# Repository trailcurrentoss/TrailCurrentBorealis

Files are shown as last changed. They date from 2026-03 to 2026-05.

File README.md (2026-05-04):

# TrailCurrent Borealis

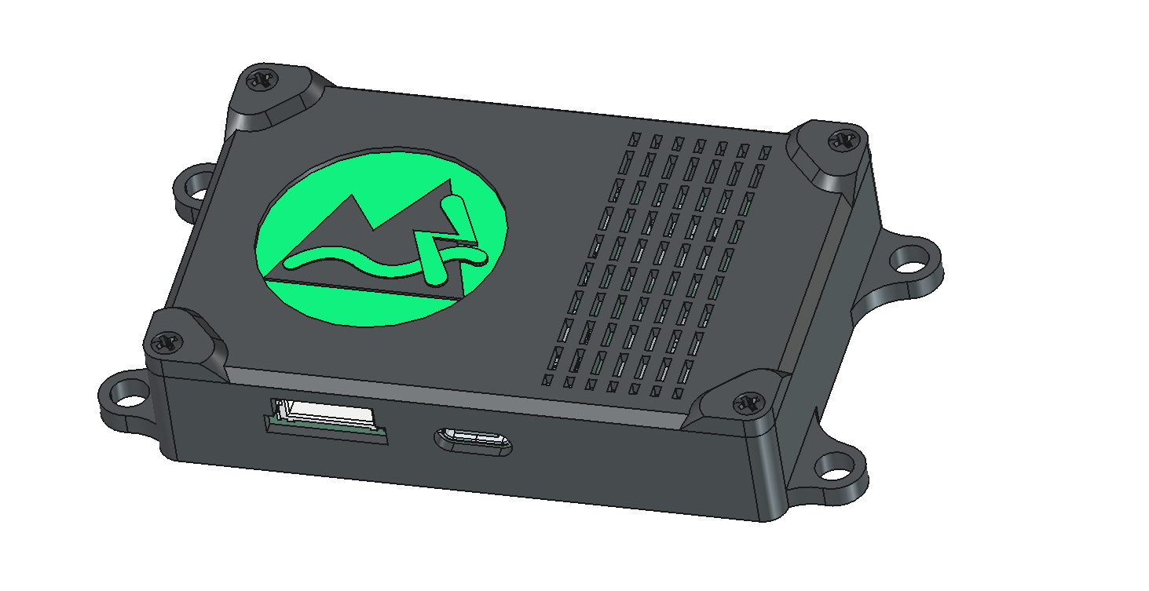
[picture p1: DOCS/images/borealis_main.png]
TrailCurrent Borealis


Environmental and safety sensor node for toy haulers, RVs, and similar enclosed living spaces. Measures temperature, humidity, real CO2, VOC index, carbon monoxide, and propane / LPG levels, then broadcasts readings over a CAN bus. Supports over-the-air (OTA) firmware updates, WiFi credential provisioning via CAN, and network discovery for integration with TrailCurrent Headwaters.

## Hardware

- **MCU board:** [Waveshare ESP32-S3-RS485-CAN](https://www.waveshare.com/esp32-s3-rs485-can.htm)
  - ESP32-S3R8 (8MB PSRAM, external 16MB flash)
  - Built-in isolated CAN transceiver (TJA1051) on GPIO15/16
  - Built-in isolated RS485 transceiver (unused by Borealis)
  - External PCF85063AT RTC
  - 7-36V DC input or 5V USB-C
- **CO2 / temp / humidity:** DFRobot SEN0536 (Sensirion SCD41, photoacoustic NDIR)
- **VOC trending:** DFRobot SEN0394 (Sensirion SGP40, VOC Index 1-500)
- **Carbon monoxide:** DFRobot SEN0466 (factory-calibrated electrochemical, 0-1000 ppm)
- **Propane / LPG:** DFRobot SEN0131 (MQ-6 with adjustable potentiometer)

### Pin Assignments

| GPIO | Function |
|---|---|
| 5 | I2C SDA (SCD41, SGP40, SEN0466) |
| 6 | I2C SCL (SCD41, SGP40, SEN0466) |
| 3 | MQ-6 analog input (ADC1_CH2, via 10k/15k divider) |
| 15 | CAN TX (internal transceiver) |
| 16 | CAN RX (internal transceiver) |

See [`DOCS/sensor-wiring.md`](DOCS/sensor-wiring.md) for full wiring details and the [ribbon-cable diagram](DOCS/borealis-ribbon-cable.svg). When the parts arrive, work through [`DOCS/arrival-todos.md`](DOCS/arrival-todos.md) for the assembly, calibration, and validation checklist.

### Circuit Notes

- KiCad schematic and PCB files are in the `EDA/` directory
- The MQ-6 sensor's analog output swings 0-5V; a 10kΩ + 15kΩ resistor divider scales it to 0-3V at the ADC pin
- Add a 100nF cap from the ADC pin to GND for noise filtering near the heater

## Building

This project uses [ESP-IDF](https://docs.espressif.com/projects/esp-idf/en/stable/esp32s3/get-started/index.html) (v5.x).

```bash
# Configure (first time only)
idf.py set-target esp32s3

# Build
idf.py build

# Flash via USB
idf.py flash

# Monitor serial output
idf.py monitor

# Build, flash, and monitor in one step
idf.py build flash monitor
```

### OTA Upload

```bash
curl -X POST http://<hostname>.local/ota --data-binary @build/borealis.bin
```

## Architecture

| File | Purpose |
|---|---|
| `main/main.c` | Sensor reading loop, TWAI task, CAN frame transmission |
| `main/sensors.c/h` | I²C drivers for SCD41, SGP40, SEN0466; ADC reading and Rs/R0 calculation for MQ-6 |
| `main/wifi_config.c/h` | NVS-backed WiFi credentials and STA connect/disconnect |
| `main/ota.c/h` | HTTP POST `/ota` server, runs in dedicated task |
| `main/discovery.c/h` | mDNS-based network discovery for Headwaters registration |

### CAN Bus Task

The TWAI (CAN) driver runs in a dedicated FreeRTOS task with alert-based message handling. It uses a dual-state transmission model:

- **TX_ACTIVE** (1000 ms period): Normal operation when peers are detected on the bus
- **TX_PROBING** (2000 ms period): Slow probe when no peers are ACKing, reduces bus noise

The task automatically transitions between states based on TX success/failure and incoming messages. Bus-off recovery is handled via TWAI alerts. This pattern is shared with all other TrailCurrent ESP-IDF modules — see `TrailCurrentReservoir`, `TrailCurrentSwitchback`, etc.

## CAN Bus Protocol

All communication uses a 500 kbps CAN bus. The device transmits sensor data and receives OTA / WiFi / discovery commands.

### Environmental Data (TX)

**CAN ID:** `0x1F` | **DLC:** 8 | **Period:** 1000 ms

| Byte | Content |
|---|---|
| 0 | Temperature (°C, signed int8, rounded) |
| 1 | Temperature (°F, signed int8, rounded) |
| 2-3 | Humidity (big-endian uint16, value × 100, e.g. 4523 = 45.23%) |
| 4-5 | Real CO2 in ppm (big-endian uint16, NDIR measurement from SCD41) |
| 6-7 | VOC Index (big-endian uint16, range 1-500, baseline ≈ 100) |

### Safety Data (TX)

**CAN ID:** `0x20` | **DLC:** 8 | **Period:** 1000 ms

| Byte | Content |
|---|---|
| 0-1 | CO concentration in ppm (big-endian uint16) |
| 2-3 | LPG / propane Rs/R0 ratio × 1000 (big-endian uint16; lower = more gas) |
| 4 | Alarm flags (bitmask) |
| 5-7 | Reserved |

Alarm flag bits:
- `0x01` CO warning (≥ 70 ppm)
- `0x02` CO alarm (≥ 200 ppm)
- `0x04` LPG warning (Rs/R0 < 0.5)
- `0x08` LPG alarm (Rs/R0 < 0.3)
- `0x10` CO2 warning (≥ 1500 ppm)
- `0x20` CO2 alarm (≥ 2500 ppm)
- `0x40` VOC alarm (Index ≥ 400)

### OTA Trigger (RX)

**CAN ID:** `0x00` | **DLC:** 3+

| Byte | Content |
|---|---|
| 0-2 | Target MAC suffix (e.g., `F2 7E 6C` for hostname `esp32-F27E6C`) |

When the MAC matches, the device connects to its configured WiFi network, starts an HTTP server at `/ota`, and waits for a firmware upload for 3 minutes before returning to normal operation.

### WiFi Configuration (RX)

**CAN ID:** `0x01` | **DLC:** varies

WiFi credentials are provisioned over CAN using a chunked protocol. Credentials are stored in NVS (non-volatile storage) and persist across reboots.

| Byte 0 | Message Type |
|---|---|
| `0x01` | Start: contains SSID length, password length, chunk counts |
| `0x02` | SSID chunk: 6-byte payload with chunk index |
| `0x03` | Password chunk: 6-byte payload with chunk index |
| `0x04` | End: contains XOR checksum for validation |

The protocol includes a 5-second timeout — if chunks stop arriving, the state resets.

### Discovery Trigger (RX)

**CAN ID:** `0x02` | **DLC:** any (broadcast)

When received, the device connects to WiFi and advertises itself via mDNS (`_trailcurrent._tcp`) with TXT records:

| Key | Value |
|-----|---|
| `type` | `borealis` |
| `canid` | `0x1F` |
| `fw` | firmware version |

Headwaters confirms registration by calling `GET /discovery/confirm`. The discovery window is 3 minutes.

### Firmware Version Report (TX)

**CAN ID:** `0x04` | **DLC:** 6

Sent once on boot after CAN initialization, then again whenever a peer is first detected. Reports the running firmware version so Headwaters can track what each device is running.

| Byte | Content |
|---|---|
| 0-2 | Last 3 bytes of device WiFi MAC (matches hostname `esp32-XXYYZZ`) |
| 3 | Version major |
| 4 | Version minor |
| 5 | Version patch |

## Air Quality and Safety Thresholds

### Real CO2 (SCD41, NDIR)

| ppm | Level |
|-----|---|
| < 800 | Fresh / well-ventilated |
| 800-1499 | Normal indoor |
| 1500-2499 | Stuffy / drowsiness possible |
| ≥ 2500 | Alarm |

### VOC Index (SGP40)

| Index | Meaning |
|---|---|
| 1-99 | Better than recent baseline |
| 100 | Typical indoor air (24-hour running average) |
| 101-249 | Worse than baseline |
| 250-399 | Significant pollution event |
| 400-500 | Severe pollution event |

### Carbon Monoxide (SEN0466)

| ppm | Level |
|-----|---|
| < 35 | Normal |
| 35-69 | Elevated |
| 70-199 | Warning |
| ≥ 200 | Alarm |

### Propane / LPG (MQ-6, Rs/R0 ratio)

| Rs/R0 | Level |
|---|---|
| > 0.7 | Clean air |
| 0.5-0.7 | Trace |
| 0.3-0.5 | Warning |
| < 0.3 | Alarm |

The MQ-6 outputs a resistance ratio rather than ppm; calibrating to absolute ppm requires tank-test exposure. For leak detection the ratio is what matters: a sharp drop from baseline indicates propane present.

## OTA Updates

1. Provision WiFi credentials via CAN (one-time setup, stored in NVS)
2. Send an OTA trigger message on CAN ID `0x00` with the target device's MAC suffix
3. The device connects to WiFi
4. Upload firmware via HTTP: `curl -X POST http://<hostname>.local/ota --data-binary @build/borealis.bin`
5. On success, the device reboots with new firmware
6. On timeout (3 minutes), the device disconnects WiFi and resumes normal operation

The device hostname is printed to serial at boot (format: `esp32-XXYYZZ`).

## License

[MIT](LICENSE)

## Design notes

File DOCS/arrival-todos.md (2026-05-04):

# Parts-Arrival TODO Checklist

Tasks to complete once the DFRobot sensors and Waveshare board arrive. The firmware is already written and builds clean — these are the hardware, calibration, and validation steps that can only be done with physical parts.

## Hardware to assemble

- [ ] **MQ-6 voltage divider**: solder 10kΩ + 15kΩ resistors between MQ-6 SIG and IO3, with 15kΩ to GND. See wiring diagram in [`sensor-wiring.md`](sensor-wiring.md).
- [ ] **MQ-6 ADC noise filter**: add 100nF ceramic cap from IO3 to GND.
- [ ] **Ribbon cable** (or carrier PCB): wire per [`borealis-ribbon-cable.svg`](borealis-ribbon-cable.svg).
- [ ] **Verify DFRobot Gravity cable wire colors** match the assumption in `sensor-wiring.md` (red=VCC, black=GND, blue/yellow=SDA/SIG, white/green=SCL). Update the doc if vendor swapped them.
- [ ] **CAN bus termination**: close H1 jumper on the Waveshare board if Borealis is at one end of the bus.
- [ ] **Mount MQ-6 low** (10-30 cm off the floor) — propane is heavier than air and pools.
- [ ] **Mount SCD41 at sleeping-zone height** (1-1.5 m off the floor).

## First power-up validation

- [ ] **VIN power**: feed 12V from RV house battery (or 5V via USB-C) and verify it boots.
- [ ] **Multimeter check on the breakout header**: Pin 1 = 3.3V, Pin 2 = 5V, IO3 < 3.0V (if it shows 5V, the divider isn't installed and the ADC is already damaged).
- [ ] **Serial log check**: confirm all four sensors attach. Look for these lines:
  - `SCD41 attached (0x62)`
  - `SGP40 attached (0x59)`
  - `SEN0466 CO sensor attached (0x74)`
  - `MQ-6 ADC ready on GPIO3 (channel 2)`
- [ ] **Hostname** is logged at boot: format `esp32-XXYYZZ`.
- [ ] **CAN frames** are visible on the bus (use Headwaters or a CAN sniffer). Expect 0x1F (environmental) and 0x20 (safety) every 1 s.

## MQ-6 burn-in and R0 calibration

- [ ] Leave the unit powered in clean air (open garage, outdoor, well-ventilated room) for **24-48 hours** continuously. Do not trust gas readings during this window.
- [ ] After burn-in, trigger `mq6_calibrate_r0()` — currently a code-side function call. Either:
  - Add a temporary CAN message handler that calls it, or
  - Add a button-press handler on GPIO0 (the boot button), or
  - Manually call it once via a debug serial command path.
- [ ] Confirm the log shows `MQ-6 R0 calibrated: X.XX kΩ` and that R0 persists across reboots (`MQ-6 R0 loaded from NVS`).
- [ ] Verify Rs/R0 reads ~1.0 in clean air after calibration. If it drifts < 1.0 quickly without gas present, R0 was captured under poor conditions — recalibrate.

## SCD41 sanity check

- [ ] Take the device outdoors briefly. CO2 should drop toward ~420 ppm (current outdoor baseline).
- [ ] Compare reported temperature against a reference thermometer; ±0.8°C is in spec but anything wider suggests a defective unit.
- [ ] **Decide on auto-self-calibration**:
  - Toy hauler that's parked outdoors when not in use → leave ASC on (default).
  - Always-occupied installation → call `scd41_set_automatic_self_calibration(false)` to turn off (function not yet in driver — add when needed).

## SEN0466 CO sensor warmup

- [ ] First power-up after factory shipping: leave running for **~1 hour** before trusting low-ppm readings. Electrochemical cells take time to stabilize.
- [ ] Confirm 0 ppm baseline in clean air.
- [ ] *Optional:* test with a controlled CO source (camp stove exhaust briefly directed at sensor) to confirm response. Be careful — actual CO is dangerous.

## SGP40 production VOC algorithm

The current [`sgp40_estimate_index()`](../main/sensors.c) is a placeholder with a 17-minute baseline. Replace it for production:

- [ ] Add Sensirion's [`embedded-gas-index-algorithm`](https://github.com/Sensirion/gas-index-algorithm) (BSD-3 licensed) to the project.
  - Either as a managed component (if Sensirion publishes one), or
  - Drop the C source files into `components/sensirion_gas_index/` and add a `CMakeLists.txt`.
- [ ] Replace the stub function body in `sensors.c` with calls to:
  - `GasIndexAlgorithm_init(&params, GasIndexAlgorithm_ALGORITHM_TYPE_VOC)`
  - `GasIndexAlgorithm_process(&params, sraw, &voc_index)`
- [ ] Confirm baseline settles to ~100 after 24 hours of operation.

## CAN integration with Headwaters

- [ ] Provision WiFi credentials via CAN ID 0x01 (see chunked protocol in README).
- [ ] Trigger discovery via CAN ID 0x02; verify Borealis advertises on mDNS as `_trailcurrent._tcp` with `type=borealis canid=0x1F`.
- [ ] Verify Headwaters confirms via `GET /discovery/confirm` (look for `Discovery confirmed by Headwaters` in the serial log).
- [ ] Test OTA upload: `curl -X POST http://esp32-XXYYZZ.local/ota --data-binary @build/borealis.bin`. After the device reboots, the firmware version frame on CAN ID 0x04 should reflect the new version.

## Threshold validation

The README documents these thresholds; verify they fire correctly in the field:

- [ ] **CO ≥ 70 ppm** → bit 0 set in safety frame byte 4.
- [ ] **CO ≥ 200 ppm** → bit 1 set.
- [ ] **MQ-6 Rs/R0 < 0.5** → bit 2 set (LPG warning).
- [ ] **MQ-6 Rs/R0 < 0.3** → bit 3 set (LPG alarm).
- [ ] **CO2 ≥ 1500 ppm** → bit 4 set.
- [ ] **CO2 ≥ 2500 ppm** → bit 5 set.
- [ ] **VOC index ≥ 400** → bit 6 set.

Easy way to test without real gas: temporarily inject test values via a debug CAN message or hardcode a high reading for one cycle, and confirm Headwaters' alarm path triggers.

## Power and thermal validation

- [ ] At **12V VIN**: measure current draw. Expect ~150-250 mA average (mostly the MQ-6 heater).
- [ ] After 1 hour of operation, **feel the buck regulator** (XL1509 area on the board). Should be warm, not painfully hot. > ~65°C calls for a heat sink or duty-cycling the MQ-6.
- [ ] *Optional:* repeat at 24V VIN if you'll be running on a 24V system. Expect more regulator heat.

## Documentation updates after validation

- [ ] Update `sensor-wiring.md` if any wire colors / connector orientations differ from what's documented.
- [ ] Update the threshold tables in `README.md` if field testing suggests different alarm levels.
- [ ] Photograph the assembled unit and add to `DOCS/images/` for the README header.
- [ ] Note any sensor quirks observed (e.g. SGP40 spike on cold boot, SCD41 needing pressure compensation at high altitude) in this checklist's "Known issues" section below.

## Known issues / observations

*(Fill in during commissioning)*

- _none yet_

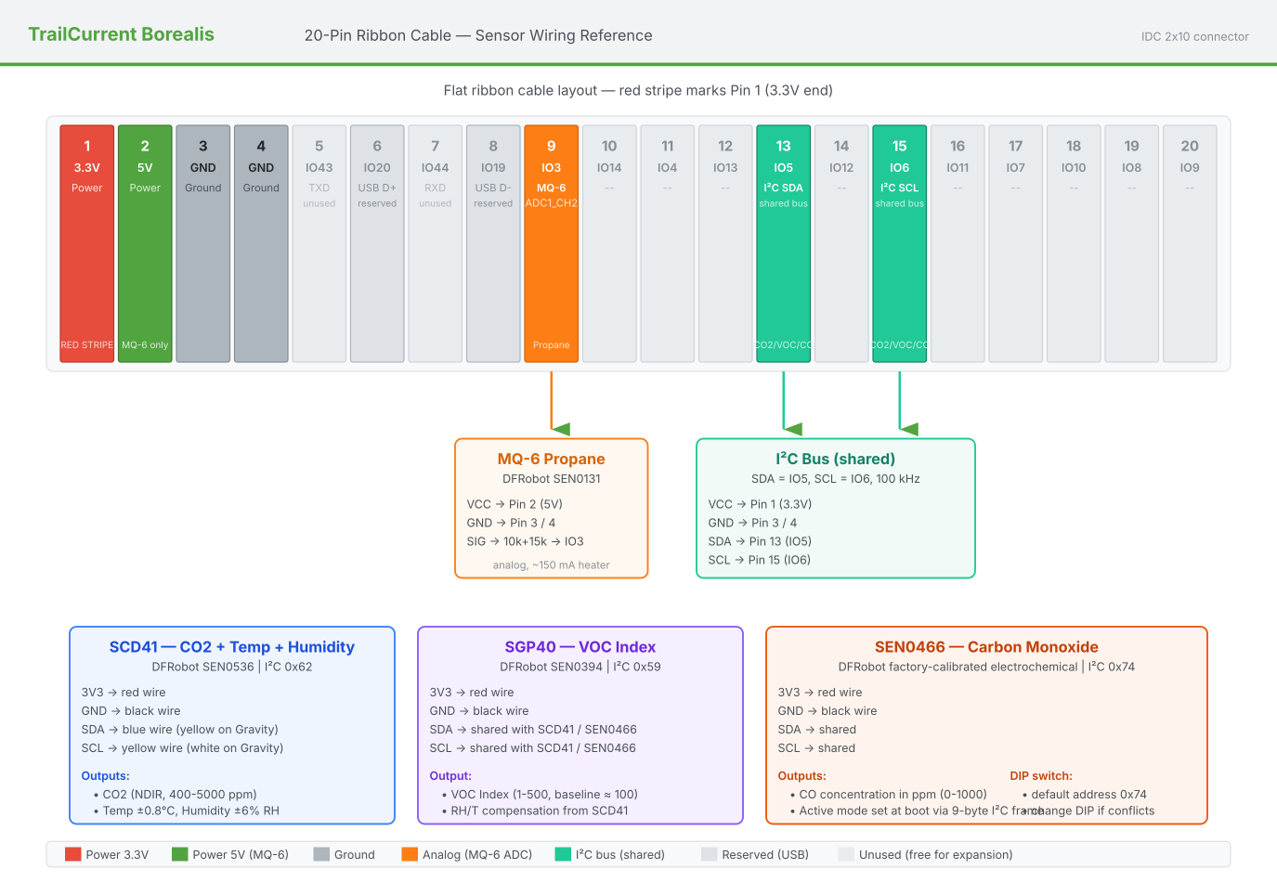
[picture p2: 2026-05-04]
DOCS/borealis-ribbon-cable.png

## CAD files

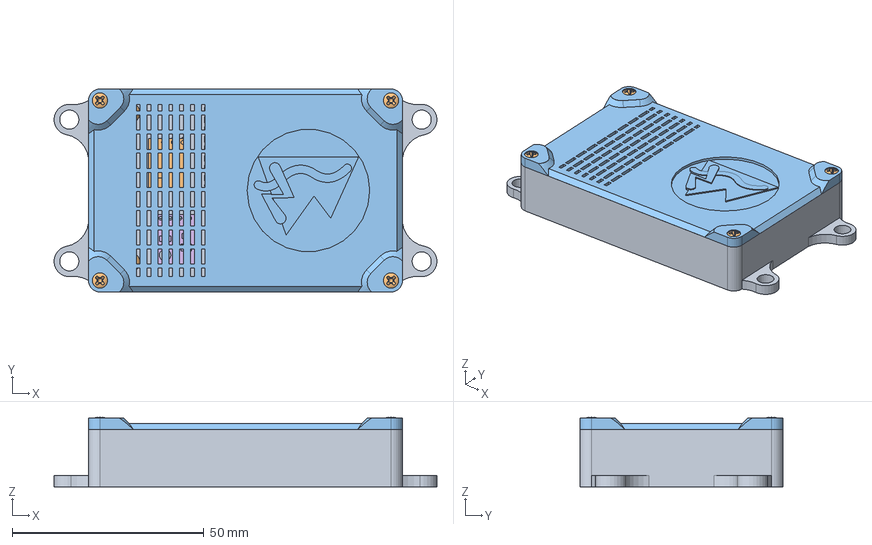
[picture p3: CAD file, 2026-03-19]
CAD/TrailCurrentBorealisCase.FCStd
100.0 x 53.0 x 18.2 mm
BodyBorealisCaseBottom
SHT31-D-TempHumidity
BODY-SO
LEAD-D0008A
LEAD-D0008A001
LEAD-D0008A002
LEAD-D0008A003
LEAD-D0008A004
LEAD-D0008A005
LEAD-D0008A006
LEAD-D0008A007
R_1206_3216Metric
JST_XH_S4B-XH-SM4-TB_1x04-1MP_P2.50mm_Horizontal
GY-SGP30
Mini560
TrailCurrentBorealis 1.7.1
TrailCurrentBorealis_PCB
2.5 mmx5-Screw x 8
BodyBorealisCaseCover

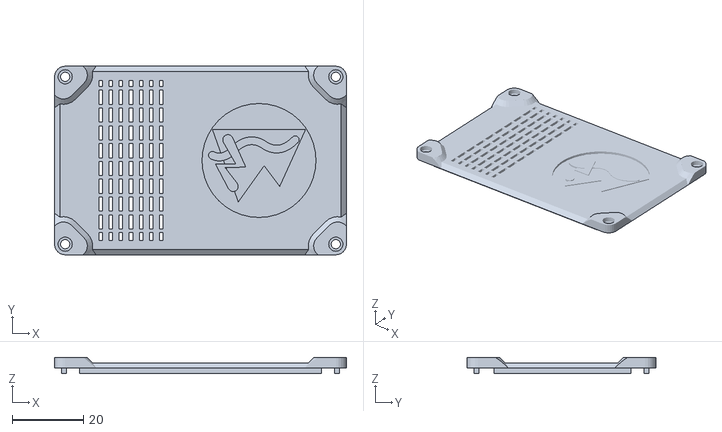
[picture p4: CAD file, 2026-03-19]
CAD/BodyBorealisCaseCoverV3.stl
82.0 x 53.0 x 4.50

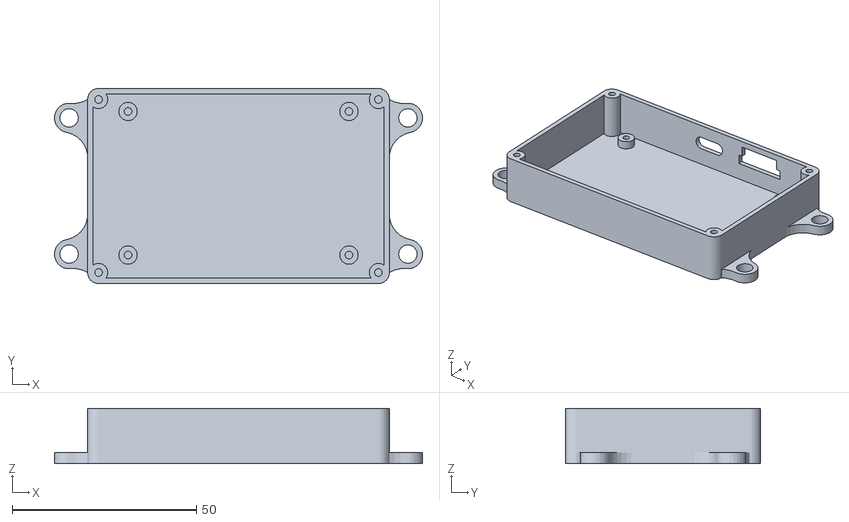
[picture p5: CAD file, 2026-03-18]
CAD/BodyBorealisCaseBottomV2.stl
100.0 x 53.0 x 15.0

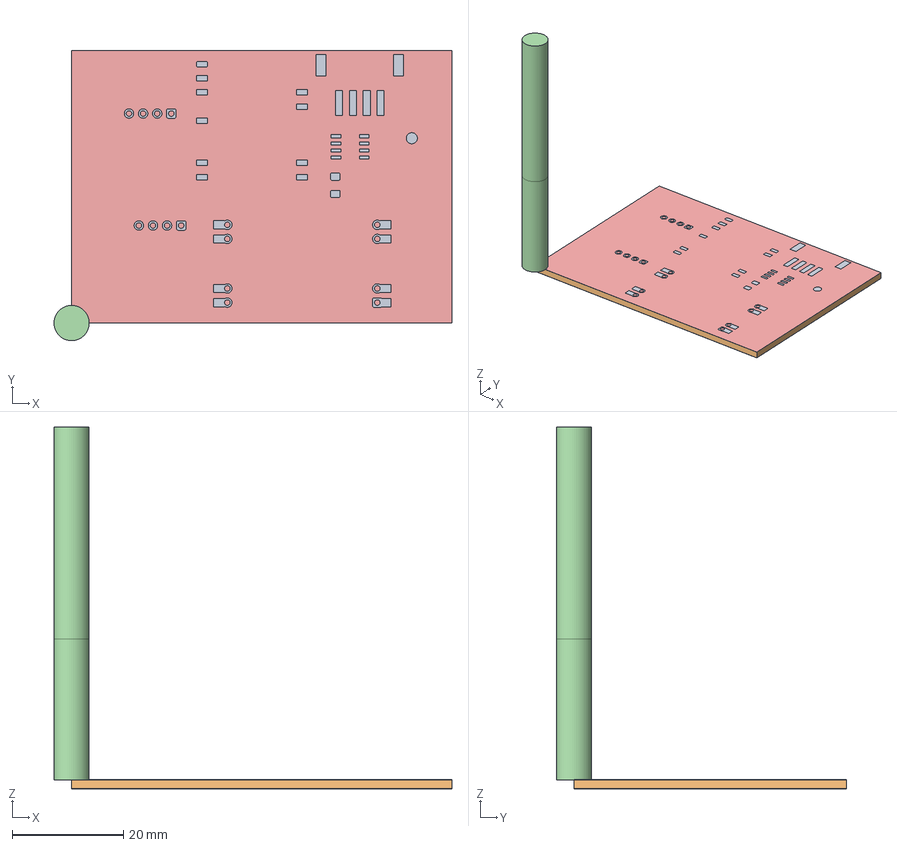
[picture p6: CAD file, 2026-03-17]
CAD/TrailCurrentBorealisPcbForMilling.FCStd
71.7 x 52.3 x 65.1 mm
Model-TrailCurrentBorealis001
Pcb_b5e1
topTracks_b5e1
SpeTool O Flute 1/4"001
Stock001
0.6mm Drill
1mm Drill001
2.5mm Drillbit001
topPads_b5e1
botPads_b5e1
botZones_b5e1

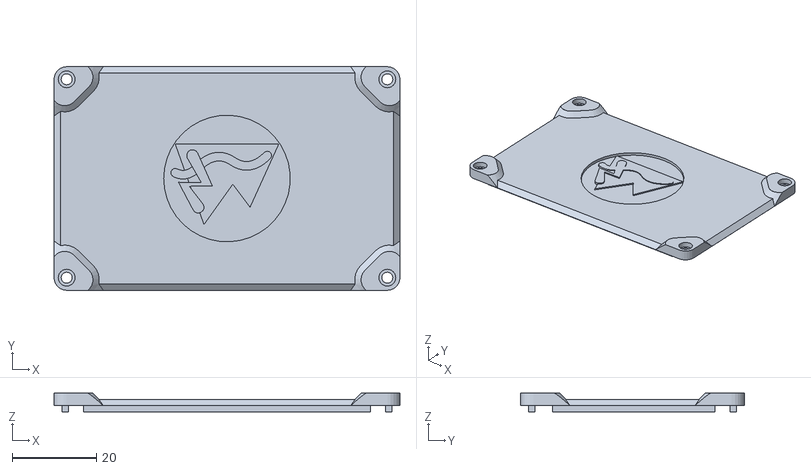
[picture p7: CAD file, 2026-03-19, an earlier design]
CAD/BodyBorealisCaseCoverV1.stl
82.0 x 53.0 x 4.50

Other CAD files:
CAD/BodyBorealisCaseCoverV2.stl
CAD/TrailCurrentBorealisCase.3mf

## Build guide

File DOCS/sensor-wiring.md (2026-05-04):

# Sensor Wiring Guide

## Sensor Overview

Borealis monitors the four most common dangers in an enclosed living space (toy hauler, RV bedroom, sealed cabin) using four DFRobot Gravity sensor modules. All four are wired to a single 20-pin IDC ribbon cable that plugs into the Waveshare ESP32-S3-RS485-CAN's user header.

| Module | Measures | DFRobot SKU | Interface | Address |
|---|---|---|---|---|
| SCD41 | Real CO2 (NDIR) + temperature + humidity | SEN0536 | I²C | 0x62 |
| SGP40 | VOC index (1-500) | SEN0394 | I²C | 0x59 |
| SEN0466 | Carbon monoxide (factory-calibrated electrochemical) | SEN0466 | I²C | 0x74 |
| MQ-6 | Propane / LPG / butane | SEN0131 | Analog | — |

Three of the four are I²C, sharing one bus. The MQ-6 is analog and uses one ADC pin.

## Wiring Diagram

See [`borealis-ribbon-cable.svg`](borealis-ribbon-cable.svg) (or [PNG](borealis-ribbon-cable.png)) for the complete pin layout.

### Pin Assignments

| IDC Pin | GPIO | Signal | Connects to |
|---|---|---|---|
| 1 | — | 3.3V | SCD41, SGP40, SEN0466 VCC (red wires) |
| 2 | — | 5V | MQ-6 VCC only |
| 3 | — | GND | All sensor GNDs |
| 4 | — | GND | All sensor GNDs |
| 9 | IO3 | MQ-6 analog | MQ-6 SIG (via 10k+15k divider) |
| 13 | IO5 | I²C SDA | SCD41 / SGP40 / SEN0466 SDA |
| 15 | IO6 | I²C SCL | SCD41 / SGP40 / SEN0466 SCL |

All other pins are unused or reserved for the board's USB.

### Power

- **3.3V (Pin 1)** powers the three I²C sensors. They have onboard regulators that accept 3.3V or 5V; using 3.3V keeps the LDO load lower and reduces noise.
- **5V (Pin 2)** powers the MQ-6 *only*. The MQ-6 heater requires 5V to reach the correct sensing temperature; running it at 3.3V gives meaningless readings.
- **GND (Pins 3, 4)** are tied together internally. Use either one — it's the same net.

### MQ-6 Voltage Divider (CRITICAL)

The MQ-6 module's SIG pin outputs 0-5V proportional to gas concentration. Connecting it directly to a 3.3V GPIO will damage the ESP32-S3 ADC.

```
MQ-6 SIG ──[ R1 = 10kΩ ]──┬──► IO3 (ADC)
                          │
                       [ R2 = 15kΩ ]
                          │
                         GND
```

Ratio = 15 / (10 + 15) = 0.6, giving 5.0V × 0.6 = 3.0V max at the ADC pin (well under the ESP32-S3 ADC's 3.1V limit at 12 dB attenuation). The firmware multiplies the measured voltage by 1/0.6 to recover the original 0-5V signal before computing Rs/R0.

Optional but recommended: a 100 nF ceramic cap from IO3 to GND for noise filtering near the heater.

### I²C Bus Topology

All three I²C sensors share GPIO5 (SDA) and GPIO6 (SCL). Each sensor's onboard regulator and pull-ups handle the bus electrically, and the addresses don't conflict:

| Address | Sensor |
|---|---|
| 0x59 | SGP40 |
| 0x62 | SCD41 |
| 0x74 | SEN0466 (default; configurable via DIP switch) |

If you use the Adafruit STEMMA-QT versions instead of DFRobot Gravity, you can chain them via the QT cables — same bus, no rewiring.

### Per-Sensor Wire Map (DFRobot Gravity 4-pin JST-PH)

DFRobot Gravity I²C cables use this color order (verify against your specific cable — vendors occasionally swap):

| DFRobot wire | Signal | IDC pin |
|---|---|---|
| Red | VCC (3.3V or 5V) | 1 (or 2 for MQ-6) |
| Black | GND | 3 or 4 |
| Yellow / Blue | SDA | 13 |
| White / Green | SCL | 15 |

For the MQ-6 (3-pin Gravity analog cable):

| DFRobot wire | Signal | IDC pin |
|---|---|---|
| Red | VCC (5V) | 2 |
| Black | GND | 3 or 4 |
| Blue / Yellow | SIG | 9 (via divider) |

## CAN Bus Wiring

The CAN bus uses the onboard TJA1051 transceiver (galvanically isolated from the MCU side):

| J5 terminal | Connection |
|---|---|
| CANH | CAN bus high wire |
| CANL | CAN bus low wire |

A 120-ohm termination resistor is required at each end of the bus. The board has an onboard 120Ω termination jumper (H1) — close it on the two devices at each end of the bus, leave it open on intermediate nodes.

## Sensor Mounting

### Placement (toy hauler / sleeping area)

| Sensor | Best location | Rationale |
|---|---|---|
| SCD41 (CO2) | Within 1-2 m of the sleeping zone, 1-1.5 m off the floor | Wants air representative of what people are breathing |
| SGP40 (VOC) | Same enclosure as SCD41 — needs RH/T compensation from it | Cross-compensation is more accurate when the two sensors share airflow |
| SEN0466 (CO) | Mid-height (1-1.5 m), away from cooking surfaces | Vehicle exhaust CO drifts through the whole space; mid-height is representative |
| MQ-6 (LPG) | **Low — near floor level** (0.1-0.3 m off the floor) | Propane is heavier than air and pools at floor level. Mounting it high will miss leaks |

### General Guidelines

1. **Ventilation** — don't seal sensors inside an airtight enclosure. They need ambient air to flow past them. A perforated case is fine.
2. **Avoid direct heat / sun** — temperature swings degrade accuracy and shorten sensor lifetime, especially the MQ-6 heater.
3. **Avoid spray contaminants** — silicones (gasket sealers, hand sanitizer), strong solvents, and chemical cleaners poison MOX gas sensors permanently. Keep the MQ-6 and SGP40 away from these.
4. **Cable length** — keep the ribbon under 1 m for clean I²C signaling at 100 kHz. Beyond ~1.5 m you may need to drop to 50 kHz in the firmware.

## First-Time Calibration

### MQ-6 Burn-in

The MQ-6's metal-oxide film needs heat-cycling to stabilize:

1. Power the unit on in clean air (e.g. open garage, outdoor air, well-ventilated room) and **leave it powered for 24-48 hours**. Don't trust readings during this window.
2. After burn-in, with the firmware running and serial connected, trigger `mq6_calibrate_r0()` to capture the clean-air baseline. (At present this is a function call you'd add manually or via a CAN message; a future build will automate it after the first 24h.)
3. Once calibrated, R0 is stored in NVS and persists across reboots. Re-calibrate yearly or after a long power-off period.

From a cold boot in subsequent sessions, the heater takes ~2-3 minutes to reach correct sensing temperature. Initial readings during this warmup will look like elevated gas — ignore the first 3 minutes after every power cycle.

### SCD41 Self-Calibration

The SCD41 has automatic self-calibration enabled by default. It assumes that during a 7-day sliding window, the lowest CO2 reading represents fresh air (~400 ppm) and corrects its zero point. For a unit installed in an always-occupied space (e.g. a permanent tow vehicle), turn this off via `scd41_set_automatic_self_calibration(false)` because the assumption breaks. For a toy hauler that's parked outdoors when not in use, leave it on.

### SGP40 Baseline

The firmware's stub VOC index estimator builds a running baseline over ~17 minutes of operation. For long-term accurate VOC trending, replace `sgp40_estimate_index()` with Sensirion's official `gas_index_algorithm` library (BSD-3 licensed, drop in via component manager). The official algorithm uses a 24-hour adaptive baseline and is what the SGP40 datasheet specifies.

## Troubleshooting

### "SCD41 attach failed" at boot

1. **Check the I²C bus** — measure SDA/SCL at the sensor with a scope. They should idle at 3.3V.
2. **Address conflict** — scan the bus with `i2cdetect`-equivalent code; verify 0x62 responds.
3. **Power** — confirm the SCD41 sees 3.3V on its VCC pin (multimeter at the breakout).
4. **Cable length / pull-ups** — the SCD41 has internal pull-ups, but adding external 4.7 kΩ pull-ups on SDA/SCL helps with longer cables or noisy environments.

### CO sensor reading 0 or NaN

1. **First 3 minutes after power-up** — electrochemical sensors stabilize over 1-3 minutes. Brand-new sensors need up to 1 hour.
2. **Check active mode** — verify the firmware sent the 0x78 0x03 command at boot. Look for `SEN0466 set to active acquisition mode` in the log.
3. **Cable / connector** — DFRobot Gravity I²C connectors are keyed; verify it's seated.
4. **Address conflict** — if you have another sensor at 0x74, change the SEN0466's DIP switch.

### MQ-6 always at full deflection (Rs/R0 < 0.3)

1. **You haven't calibrated R0 yet** — uncalibrated readings default to 1.0; if you're seeing very low ratios it means R0 was captured under non-clean-air conditions. Recalibrate in clean air.
2. **Voltage divider missing or wrong** — measure the voltage at IO3 with a multimeter. Should be < 3.0V. If it's at 5V, the divider isn't installed and the ADC is already damaged.
3. **Heater not at temperature** — first 3 minutes after cold boot will read high. Wait.
4. **Gas actually present** — if you smell propane, the sensor is doing its job. Ventilate.

### CAN Bus Not Transmitting

1. **Check J5 wiring** — CANH to CANH, CANL to CANL.
2. **Check termination** — 120Ω at each end of the bus only. The board's H1 jumper enables onboard termination.
3. **Check serial output** — look for `TWAI bus-off` or `error passive` messages. Probing mode (`entering slow probe`) is normal when no other CAN nodes are on the bus yet.
4. **Verify peer ACK** — TWAI normal mode requires at least one other CAN node to ACK frames. If Borealis is the only node on the bus, it'll cycle TX_ACTIVE → TX_PROBING.

## Modifying Pin Assignments

If you need to use different GPIOs (different sensor breakout, custom carrier PCB), edit the pin defines at the top of [`main/main.c`](../main/main.c):

```c
#define I2C_SDA_PIN          5
#define I2C_SCL_PIN          6
#define MQ6_ADC_GPIO         3   // must be on ADC1 (GPIO1-10)
```

CAN pins are hardwired to the onboard transceiver; do **not** change `CAN_TX_PIN` (15) or `CAN_RX_PIN` (16).

**Avoid these GPIOs:**
- GPIO 0: Boot strapping pin (also onboard button)
- GPIO 15: CAN TX (used by onboard transceiver)
- GPIO 16: CAN RX (used by onboard transceiver)
- GPIO 17 / 18: RS485 TX / RX (used by onboard transceiver)
- GPIO 19-20: USB D-/D+ (used for USB CDC console)
- GPIO 21: RS485 EN (used by onboard transceiver)
- GPIO 26-32: Internal QSPI flash and PSRAM (reserved on ESP32-S3R8)

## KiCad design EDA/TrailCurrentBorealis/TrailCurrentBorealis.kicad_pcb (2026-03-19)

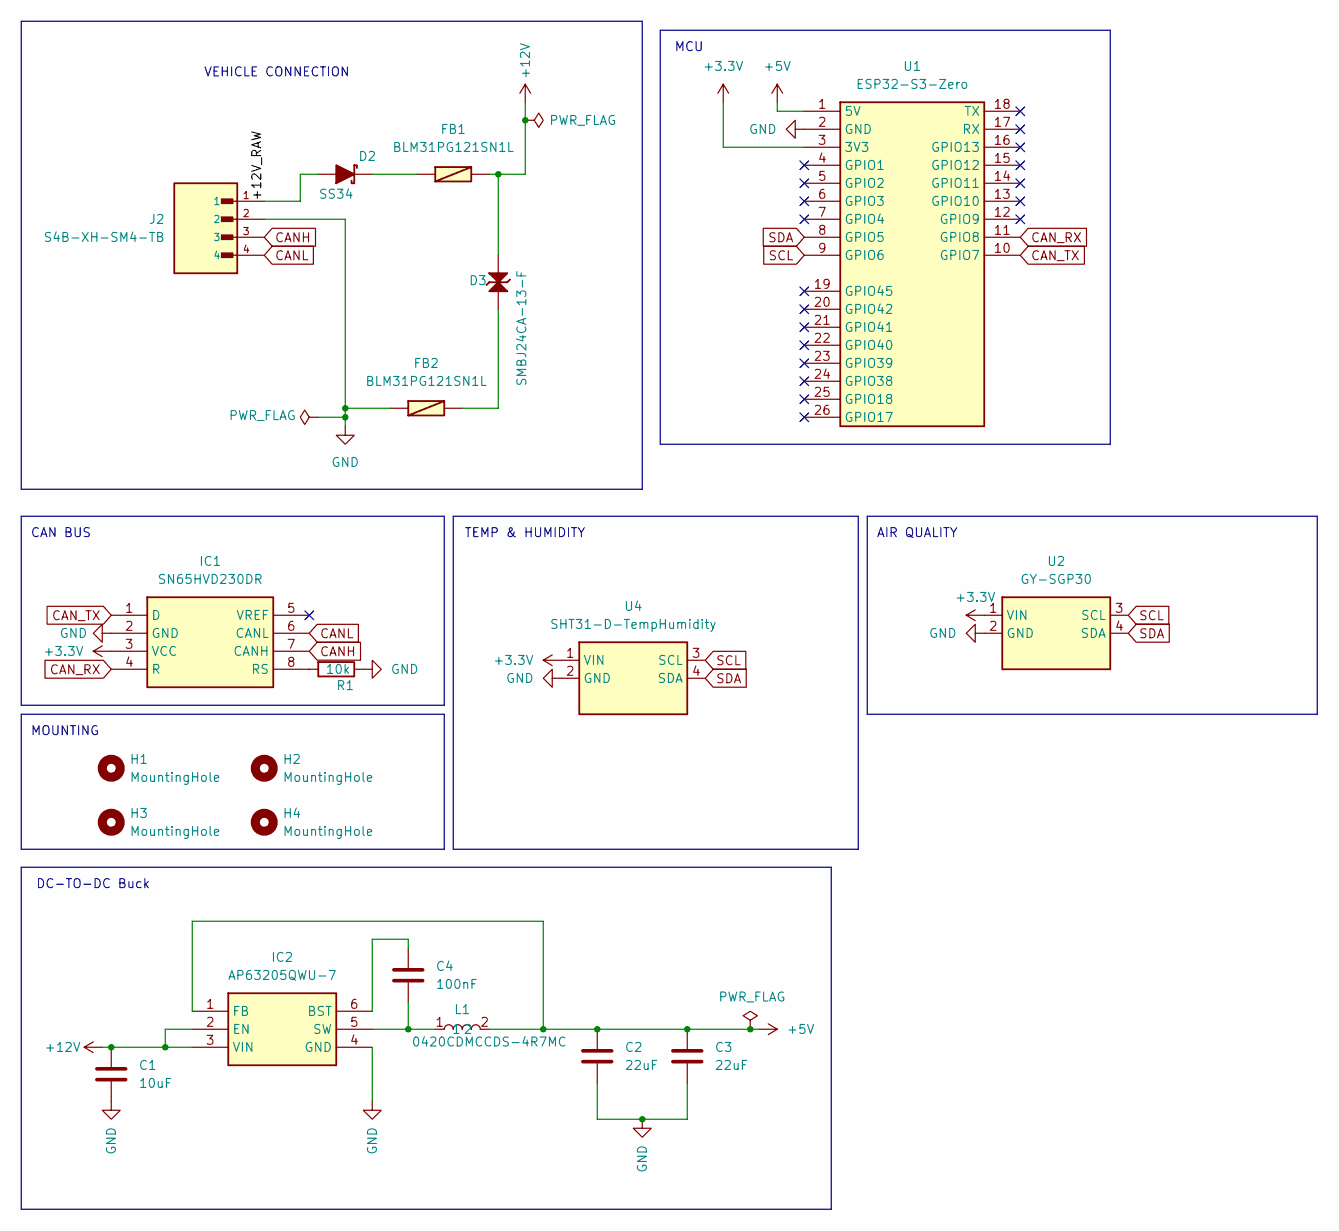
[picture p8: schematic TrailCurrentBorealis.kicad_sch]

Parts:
C1: 10uF; C_1206_3216Metric_Pad1.33x1.80mm_HandSolder
C2, C3: 22uF; C_1206_3216Metric_Pad1.33x1.80mm_HandSolder
C4: 100nF; C_1206_3216Metric_Pad1.33x1.80mm_HandSolder
D2: SS34; Manufacturer_Part_Number SS34; LCSC Part C8678
D3: SMBJ24CA-13-F; Manufacturer_Part_Number SMBJ24CA; LCSC Part C83268
FB1, FB2: BLM31PG121SN1L; Manufacturer_Part_Number BLM31PG121SN1L; LCSC Part C85841
H1, H2, H3, H4: MountingHole; MountingHole_2.5mm
IC1: SN65HVD230DR; Mouser Part Number 595-SN65HVD230DR
IC2: AP63205QWU-7; AP63205QWU7; Manufacturer_Part_Number AP63205QWU-7; LCSC Part C5248537
J2: S4B-XH-SM4-TB; JST_S4B-XH-SM4-TB; LCSC Part C161861
L1: 0420CDMCCDS-4R7MC; Manufacturer_Part_Number 0420CDMCCDS-4R7MC; LCSC Part C2638679
R1: 10k; R_1206_3216Metric_Pad1.30x1.75mm_HandSolder
U1: ESP32-S3-Zero; ESP32-S3-Zero_SMD; Manufacturer_Part_Number ESP32-S3-Zero
U2: GY-SGP30
U4: SHT31-D-TempHumidity

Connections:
+3.3V: IC1.3 (VCC), U1.3 (3V3), U2.1 (VIN), U4.1 (VIN)
+5V: C2.1, C3.1, IC2.1 (FB), L1.2, U1.1 (5V)
+12V: C1.1, D3.2, FB1.2, IC2.2 (EN), IC2.3 (VIN)
/+12V_RAW: D2.2 (A), J2.1
CANH: IC1.7 (CANH), J2.3
CANL: IC1.6 (CANL), J2.4
CAN_RX: IC1.4 (R), U1.11 (GPIO8)
CAN_TX: IC1.1 (D), U1.10 (GPIO7)
GND: C1.2, C2.2, C3.2, FB2.1, IC1.2 (GND), IC2.4 (GND), J2.2, R1.1, U1.2 (GND), U2.2 (GND), U4.2 (GND)
unnamed: D2.1 (K), FB1.1
unnamed: D3.1, FB2.2
unnamed: IC1.8 (RS), R1.2
unnamed: C4.1, IC2.6 (BST)
unnamed: C4.2, IC2.5 (SW), L1.1
SCL: U1.9 (GPIO6), U2.3 (SCL), U4.3 (SCL)
SDA: U1.8 (GPIO5), U2.4 (SDA), U4.4 (SDA)

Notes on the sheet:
VEHICLE CONNECTION
DC-TO-DC Buck
AIR QUALITY
MOUNTING
MCU
CAN BUS
TEMP & HUMIDITY

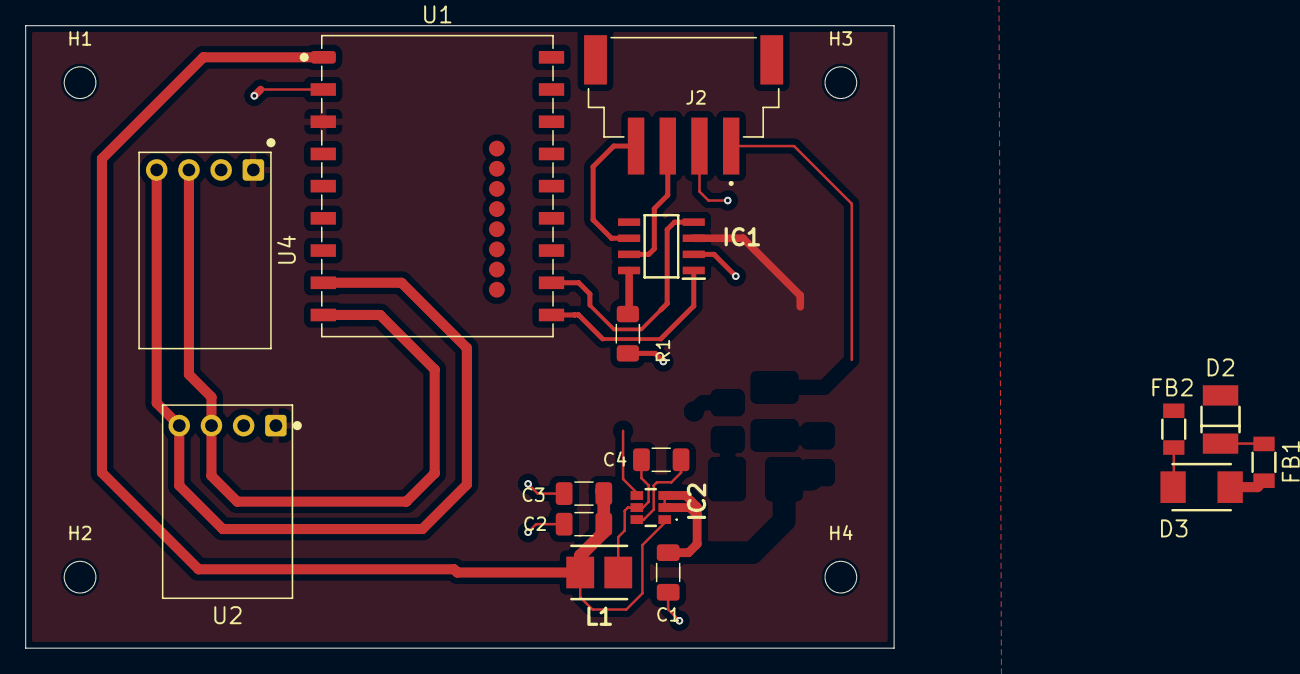
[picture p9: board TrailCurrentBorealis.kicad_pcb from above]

Board: 2 copper layers, 68.5 x 49.1 mm, 22 parts (1 on the bottom side), 16 nets.

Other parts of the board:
LOGO: TrailCurrentLogo_Text
LOGO#2: TrailCurrentLogo_Icon

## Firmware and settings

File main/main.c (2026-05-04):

#include <stdio.h>
#include <string.h>
#include "freertos/FreeRTOS.h"
#include "freertos/task.h"
#include "driver/twai.h"
#include "esp_log.h"
#include "esp_timer.h"
#include "can_common.h"
#include "wifi_config.h"
#include "ota.h"
#include "discovery.h"
#include "sensors.h"

static const char *TAG = "borealis";

// Waveshare ESP32-S3-RS485-CAN pin assignments
#define I2C_SDA_PIN          5
#define I2C_SCL_PIN          6
#define MQ6_ADC_GPIO         3   // ADC1_CH2 via 10k+15k divider
#define CAN_RX_PIN           16  // hardwired internal
#define CAN_TX_PIN           15  // hardwired internal

// CAN protocol IDs (match sibling-project conventions)
#define CAN_ID_OTA               0x00
#define CAN_ID_WIFI_CONFIG       0x01
#define CAN_ID_DISCOVERY_TRIGGER 0x02
#define CAN_ID_ENVIRONMENTAL     0x1F
#define CAN_ID_SAFETY            0x20

// Periods
#define CAN_STATUS_PERIOD_MS  1000
#define TX_PROBE_INTERVAL_MS  2000
#define SENSOR_READ_INTERVAL_MS 5000  // SCD41 periodic = 5s

// Alarm thresholds (match README)
#define CO_PPM_WARNING        70
#define CO_PPM_ALARM          200
#define LPG_RATIO_WARNING_X1000  500   // Rs/R0 < 0.5
#define LPG_RATIO_ALARM_X1000    300   // Rs/R0 < 0.3
#define CO2_PPM_WARNING       1500
#define CO2_PPM_ALARM         2500
#define VOC_INDEX_ALARM       400

#define ALARM_FLAG_CO_WARN     0x01
#define ALARM_FLAG_CO_ALARM    0x02
#define ALARM_FLAG_LPG_WARN    0x04
#define ALARM_FLAG_LPG_ALARM   0x08
#define ALARM_FLAG_CO2_WARN    0x10
#define ALARM_FLAG_CO2_ALARM   0x20
#define ALARM_FLAG_VOC_ALARM   0x40

// ---------------------------------------------------------------------------
// Shared sensor data (written by main task, read by TWAI task)
// ---------------------------------------------------------------------------

static volatile int8_t   s_temp_c_int;
static volatile int8_t   s_temp_f_int;
static volatile uint16_t s_humidity_scaled;
static volatile uint16_t s_co2_ppm;
static volatile uint16_t s_voc_index;

static volatile uint16_t s_co_ppm;
static volatile uint16_t s_lpg_rs_r0_x1000;
static volatile uint8_t  s_alarm_flags;

static volatile bool s_env_valid    = false;
static volatile bool s_safety_valid = false;

// ---------------------------------------------------------------------------
// TWAI (CAN) task — independent FreeRTOS task following the canonical
// TX_ACTIVE / TX_PROBING state machine used across all TrailCurrent modules.
// ---------------------------------------------------------------------------

static void twai_task(void *arg)
{
    // Configure alerts BEFORE any bus activity so no error transitions are missed.
    twai_reconfigure_alerts(CAN_COMMON_ALERTS, NULL);

    // Alerts armed — version broadcast TX failure is caught by the state machine.
    can_common_version_broadcast();

    typedef enum { TX_ACTIVE, TX_PROBING } tx_state_t;
    bool bus_off = false;
    tx_state_t tx_state = TX_ACTIVE;
    int tx_fail_count = 0;
    const int TX_FAIL_THRESHOLD = 3;
    int64_t last_tx_us = 0;
    const int64_t tx_period_us = CAN_STATUS_PERIOD_MS * 1000LL;
    const int64_t tx_probe_period_us = TX_PROBE_INTERVAL_MS * 1000LL;

    while (1) {
        uint32_t triggered;
        twai_read_alerts(&triggered, pdMS_TO_TICKS(CAN_STATUS_PERIOD_MS));

        // Bus-off: stop transmitting, initiate recovery
        if (triggered & TWAI_ALERT_BUS_OFF) {
            ESP_LOGE(TAG, "TWAI bus-off, initiating recovery");
            bus_off = true;
            twai_initiate_recovery();
            // No continue — fall through so RX_DATA in the same poll is still processed.
        }

        if (triggered & TWAI_ALERT_BUS_RECOVERED) {
            ESP_LOGI(TAG, "TWAI bus recovered, restarting");
            twai_start();
            bus_off = false;
            tx_fail_count = 0;
            tx_state = TX_PROBING;
        }

        if (triggered & TWAI_ALERT_ERR_PASS) {
            ESP_LOGW(TAG, "TWAI error passive (no peers ACKing?)");
        }
        if (triggered & TWAI_ALERT_TX_FAILED) {
            if (tx_state == TX_ACTIVE) {
                tx_fail_count++;
                if (tx_fail_count >= TX_FAIL_THRESHOLD) {
                    tx_state = TX_PROBING;
                    ESP_LOGW(TAG, "TWAI no peers detected, entering slow probe");
                }
            }
        }
        if (triggered & TWAI_ALERT_TX_SUCCESS) {
            if (tx_state == TX_PROBING) {
                tx_state = TX_ACTIVE;
                tx_fail_count = 0;
                can_common_version_broadcast();
                ESP_LOGI(TAG, "TWAI probe ACK'd, peer detected, resuming normal TX");
            }
            tx_fail_count = 0;
        }

        // Drain received messages and dispatch
        if (triggered & TWAI_ALERT_RX_DATA) {
            if (tx_state == TX_PROBING) {
                tx_state = TX_ACTIVE;
                tx_fail_count = 0;
                can_common_version_broadcast();
                ESP_LOGI(TAG, "TWAI peer detected via RX, resuming normal TX");
            }
            twai_message_t msg;
            while (twai_receive(&msg, 0) == ESP_OK) {
                if (msg.rtr) continue;

                switch (msg.identifier) {
                case CAN_ID_OTA:
                    if (msg.data_length_code >= 3) {
                        ota_handle_trigger(msg.data, msg.data_length_code);
                    }
                    break;

                case CAN_ID_WIFI_CONFIG:
                    if (msg.data_length_code >= 1) {
                        wifi_config_handle_can(msg.data, msg.data_length_code);
                    }
                    break;

                case CAN_ID_DISCOVERY_TRIGGER:
                    discovery_handle_trigger();
                    break;

                default:
                    break;
                }
            }
        }

        wifi_config_check_timeout();

        // Periodic transmit
        int64_t now_us = esp_timer_get_time();
        int64_t effective_period = (tx_state == TX_PROBING) ? tx_probe_period_us : tx_period_us;
        if (!bus_off && (now_us - last_tx_us >= effective_period)) {
            last_tx_us = now_us;

            if (s_env_valid) {
                uint16_t hum  = s_humidity_scaled;
                uint16_t co2  = s_co2_ppm;
                uint16_t voc  = s_voc_index;
                twai_message_t m = {
                    .identifier = CAN_ID_ENVIRONMENTAL,
                    .data_length_code = 8,
                    .data = {
                        (uint8_t)s_temp_c_int,
                        (uint8_t)s_temp_f_int,
                        (hum >> 8) & 0xFF,  hum & 0xFF,
                        (co2 >> 8) & 0xFF,  co2 & 0xFF,
                        (voc >> 8) & 0xFF,  voc & 0xFF,
                    }
                };
                twai_transmit(&m, 0);
            }

            if (s_safety_valid) {
                uint16_t co  = s_co_ppm;
                uint16_t lpg = s_lpg_rs_r0_x1000;
                twai_message_t m = {
                    .identifier = CAN_ID_SAFETY,
                    .data_length_code = 8,
                    .data = {
                        (co  >> 8) & 0xFF, co  & 0xFF,
                        (lpg >> 8) & 0xFF, lpg & 0xFF,
                        s_alarm_flags,
                        0, 0, 0,
                    }
                };
                twai_transmit(&m, 0);
            }
        }
    }
}

// ---------------------------------------------------------------------------
// Compose alarm flags from the latest sensor state
// ---------------------------------------------------------------------------

static uint8_t compute_alarm_flags(uint16_t co_ppm, uint16_t lpg_x1000,
                                   uint16_t co2_ppm, uint16_t voc_index)
{
    uint8_t f = 0;
    if (co_ppm >= CO_PPM_ALARM)         f |= ALARM_FLAG_CO_ALARM;
    else if (co_ppm >= CO_PPM_WARNING)  f |= ALARM_FLAG_CO_WARN;

    if (lpg_x1000 < LPG_RATIO_ALARM_X1000)        f |= ALARM_FLAG_LPG_ALARM;
    else if (lpg_x1000 < LPG_RATIO_WARNING_X1000) f |= ALARM_FLAG_LPG_WARN;

    if (co2_ppm >= CO2_PPM_ALARM)         f |= ALARM_FLAG_CO2_ALARM;
    else if (co2_ppm >= CO2_PPM_WARNING)  f |= ALARM_FLAG_CO2_WARN;

    if (voc_index >= VOC_INDEX_ALARM) f |= ALARM_FLAG_VOC_ALARM;
    return f;
}

// ---------------------------------------------------------------------------
// Main application
// ---------------------------------------------------------------------------

void app_main(void)
{
    ESP_LOGI(TAG, "=== TrailCurrent Borealis ===");

    // Initialize NVS, hostname, and load WiFi credentials
    ESP_ERROR_CHECK(wifi_config_init());

    char ssid[33] = {0};
    char password[64] = {0};
    if (wifi_config_load(ssid, sizeof(ssid), password, sizeof(password))) {
        ESP_LOGI(TAG, "WiFi credentials loaded from NVS");
    } else {
        ESP_LOGI(TAG, "No WiFi credentials — OTA disabled until provisioned via CAN");
    }

    discovery_init();
    ota_init();
    ESP_LOGI(TAG, "Hostname: %s", wifi_config_get_hostname());

    // CAN runs in its own task before sensors so bus errors or I²C hangs
    // never prevent CAN from operating.
    ESP_ERROR_CHECK(can_common_init(CAN_TX_PIN, CAN_RX_PIN));
    xTaskCreatePinnedToCore(twai_task, "twai", 4096, NULL, 5, NULL, 1);

    // Sensors
    if (sensors_init_i2c(I2C_SDA_PIN, I2C_SCL_PIN) != ESP_OK) {
        ESP_LOGE(TAG, "I²C init failed");
    }
    scd41_start_periodic();
    co_sen0466_set_active_mode();
    sensors_init_mq6(MQ6_ADC_GPIO);

    ESP_LOGI(TAG, "=== Setup complete ===");

    // Main loop: read sensors periodically, update shared values for CAN task.
    while (1) {
        vTaskDelay(pdMS_TO_TICKS(SENSOR_READ_INTERVAL_MS));

        scd41_data_t scd = scd41_read();
        if (scd.valid) {
            float tF = scd.temperature_c * 9.0f / 5.0f + 32.0f;
            ESP_LOGI(TAG, "SCD41: %.1f°C / %.1f°F  RH %.1f%%  CO2 %u ppm",
                     scd.temperature_c, tF, scd.humidity, scd.co2_ppm);

            s_temp_c_int = (int8_t)(scd.temperature_c + 0.5f);
            s_temp_f_int = (int8_t)(tF + 0.5f);
            s_humidity_scaled = (uint16_t)(scd.humidity * 100.0f);
            s_co2_ppm = scd.co2_ppm;
        }

        sgp40_data_t sgp = sgp40_measure(
            scd.valid ? scd.humidity : -1.0f,
            scd.valid ? scd.temperature_c : 25.0f);
        if (sgp.valid) {
            ESP_LOGI(TAG, "SGP40: VOC raw %u  index %u", sgp.voc_raw, sgp.voc_index);
            s_voc_index = sgp.voc_index;
        }

        if (scd.valid && sgp.valid) {
            s_env_valid = true;
        }

        co_data_t co = co_sen0466_read();
        if (co.valid) {
            ESP_LOGI(TAG, "CO:    %.1f ppm", co.ppm);
            s_co_ppm = (uint16_t)(co.ppm + 0.5f);
        }

        mq6_data_t mq = mq6_read();
        if (mq.valid) {
            ESP_LOGI(TAG, "MQ-6:  V=%.2fV  Rs/R0=%.2f%s",
                     mq.voltage, mq.rs_over_r0,
                     mq.calibrated ? "" : " (uncalibrated)");
            s_lpg_rs_r0_x1000 = mq.rs_over_r0_x1000;
        }

        if (co.valid || mq.valid) {
            s_alarm_flags = compute_alarm_flags(s_co_ppm, s_lpg_rs_r0_x1000,
                                                s_co2_ppm, s_voc_index);
            s_safety_valid = true;
        }
    }
}

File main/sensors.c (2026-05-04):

#include "sensors.h"

#include <string.h>
#include <math.h>
#include "freertos/FreeRTOS.h"
#include "freertos/task.h"
#include "driver/i2c_master.h"
#include "esp_adc/adc_oneshot.h"
#include "esp_adc/adc_cali.h"
#include "esp_adc/adc_cali_scheme.h"
#include "esp_log.h"
#include "nvs.h"

static const char *TAG = "sensors";

static i2c_master_bus_handle_t s_i2c_bus = NULL;
static i2c_master_dev_handle_t s_scd41_dev = NULL;
static i2c_master_dev_handle_t s_sgp40_dev = NULL;
static i2c_master_dev_handle_t s_co_dev = NULL;

// MQ-6 ADC state
static adc_oneshot_unit_handle_t s_adc_handle = NULL;
static adc_cali_handle_t s_adc_cali = NULL;
static adc_channel_t s_mq6_channel = ADC_CHANNEL_2;  // GPIO3
static bool s_mq6_initialized = false;
static float s_mq6_r0 = 0.0f;        // Rs in clean air, captured during calibration
static bool s_mq6_calibrated = false;

#define NVS_NS_MQ6        "mq6"
#define NVS_KEY_R0        "r0"

// Reference voltage / resistor used in Rs calculation. The DFRobot SEN0131
// uses a fixed RL (with potentiometer trim) on its onboard divider; we don't
// know the exact value so we use a relative ratio instead — Rs is computed
// from the assumption RL = 10kΩ (the MQ-6 datasheet typical) and then we
// rely on the Rs/R0 ratio for gas detection, which cancels out RL.
#define MQ6_VCC          5.0f
#define MQ6_RL_KOHMS     10.0f

// ADC sampling parameters (chosen, not defaulted)
//   Oversampling N=64: noise reduction ∝ √N → ~8× reduction from the ~10-20 mV
//     ADC noise floor at DB_12, leaving ~1-3 mV residual noise.  Total sample
//     time ~1.6 ms, negligible at the 5-second sensor cadence.  256 would gain
//     ~2× more but adds no practical value for this slow signal.
//   Trim N=4: discard the highest 4 and lowest 4 samples before averaging.
//     A trimmed mean is robust to occasional outliers (WiFi TX bursts, ESD,
//     supply transients) that pure mean would let propagate.  Critical for a
//     safety sensor where a single bad reading could trigger a false alarm.
//   Warmup reads N=2: the ESP32-S3 sample-and-hold capacitor charges on first
//     read after idle; the very first sample can be off.  Discard before
//     starting the measurement set.
//   V_MAX_MV=3300: 12 dB attenuation has a typical max of ~3.1V; 3.3V is a
//     conservative upper bound for sanity-rejecting nonsense readings.
#define MQ6_ADC_SAMPLES        64
#define MQ6_ADC_TRIM           4
#define MQ6_ADC_WARMUP_READS   2
#define MQ6_ADC_V_MAX_MV       3300

// ---------------------------------------------------------------------------
// CRC-8 (polynomial 0x31, init 0xFF) — used by SCD41, SGP40, and SHT-family
// ---------------------------------------------------------------------------

static uint8_t sensirion_crc8(const uint8_t *data, size_t len)
{
    uint8_t crc = 0xFF;
    for (size_t i = 0; i < len; i++) {
        crc ^= data[i];
        for (int b = 0; b < 8; b++) {
            crc = (crc & 0x80) ? (crc << 1) ^ 0x31 : (crc << 1);
        }
    }
    return crc;
}

// Send a 16-bit Sensirion command (no parameters)
static esp_err_t sensirion_send_cmd(i2c_master_dev_handle_t dev, uint16_t cmd)
{
    uint8_t buf[2] = { (cmd >> 8) & 0xFF, cmd & 0xFF };
    return i2c_master_transmit(dev, buf, 2, 1000);
}

// Send a 16-bit Sensirion command with a 16-bit parameter (with CRC)
static esp_err_t sensirion_send_cmd_with_arg(i2c_master_dev_handle_t dev,
                                             uint16_t cmd, uint16_t arg)
{
    uint8_t buf[5];
    buf[0] = (cmd >> 8) & 0xFF;
    buf[1] = cmd & 0xFF;
    buf[2] = (arg >> 8) & 0xFF;
    buf[3] = arg & 0xFF;
    buf[4] = sensirion_crc8(&buf[2], 2);
    return i2c_master_transmit(dev, buf, sizeof(buf), 1000);
}

// ---------------------------------------------------------------------------
// I²C bus setup
// ---------------------------------------------------------------------------

esp_err_t sensors_init_i2c(int sda_pin, int scl_pin)
{
    i2c_master_bus_config_t bus_cfg = {
        .i2c_port = I2C_NUM_0,
        .sda_io_num = sda_pin,
        .scl_io_num = scl_pin,
        .clk_source = I2C_CLK_SRC_DEFAULT,
        .glitch_ignore_cnt = 7,
        .flags.enable_internal_pullup = true,
    };
    esp_err_t ret = i2c_new_master_bus(&bus_cfg, &s_i2c_bus);
    if (ret != ESP_OK) {
        ESP_LOGE(TAG, "I²C bus init failed: %s", esp_err_to_name(ret));
        return ret;
    }

    i2c_device_config_t scd41_cfg = {
        .dev_addr_length = I2C_ADDR_BIT_LEN_7,
        .device_address = SCD41_ADDR,
        .scl_speed_hz = 100000,
    };
    if (i2c_master_bus_add_device(s_i2c_bus, &scd41_cfg, &s_scd41_dev) != ESP_OK) {
        ESP_LOGE(TAG, "SCD41 attach failed");
        s_scd41_dev = NULL;
    } else {
        ESP_LOGI(TAG, "SCD41 attached (0x%02X)", SCD41_ADDR);
    }

    i2c_device_config_t sgp40_cfg = {
        .dev_addr_length = I2C_ADDR_BIT_LEN_7,
        .device_address = SGP40_ADDR,
        .scl_speed_hz = 100000,
    };
    if (i2c_master_bus_add_device(s_i2c_bus, &sgp40_cfg, &s_sgp40_dev) != ESP_OK) {
        ESP_LOGE(TAG, "SGP40 attach failed");
        s_sgp40_dev = NULL;
    } else {
        ESP_LOGI(TAG, "SGP40 attached (0x%02X)", SGP40_ADDR);
    }

    i2c_device_config_t co_cfg = {
        .dev_addr_length = I2C_ADDR_BIT_LEN_7,
        .device_address = CO_SEN0466_ADDR,
        .scl_speed_hz = 100000,
    };
    if (i2c_master_bus_add_device(s_i2c_bus, &co_cfg, &s_co_dev) != ESP_OK) {
        ESP_LOGE(TAG, "SEN0466 attach failed");
        s_co_dev = NULL;
    } else {
        ESP_LOGI(TAG, "SEN0466 CO sensor attached (0x%02X)", CO_SEN0466_ADDR);
    }

    return ESP_OK;
}

// ---------------------------------------------------------------------------
// SCD41 — Sensirion photoacoustic NDIR CO2 + T + RH
// ---------------------------------------------------------------------------

#define SCD41_CMD_START_PERIODIC  0x21B1
#define SCD41_CMD_READ_MEAS       0xEC05
#define SCD41_CMD_GET_DATA_READY  0xE4B8
#define SCD41_CMD_SET_PRESSURE    0xE000
#define SCD41_CMD_STOP_PERIODIC   0x3F86

esp_err_t scd41_start_periodic(void)
{
    if (s_scd41_dev == NULL) return ESP_ERR_INVALID_STATE;
    esp_err_t ret = sensirion_send_cmd(s_scd41_dev, SCD41_CMD_START_PERIODIC);
    if (ret != ESP_OK) {
        ESP_LOGE(TAG, "SCD41 start_periodic failed: %s", esp_err_to_name(ret));
    } else {
        ESP_LOGI(TAG, "SCD41 periodic measurement started (5s update)");
    }
    return ret;
}

esp_err_t scd41_set_ambient_pressure(uint16_t pressure_hpa)
{
    if (s_scd41_dev == NULL) return ESP_ERR_INVALID_STATE;
    return sensirion_send_cmd_with_arg(s_scd41_dev, SCD41_CMD_SET_PRESSURE, pressure_hpa);
}
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

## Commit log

2026-03-07 Starting Borealis project
    [TrailCurrentBorealis.kicad_pcb, TrailCurrentBorealis.kicad_sch, partitions.csv]
2026-03-12 CAD for milling PCB on Genmistu 3030 just edges and drill holes not tracks
    [TrailCurrentBorealis.kicad_pcb, TrailCurrentBorealis.kicad_sch, TrailCurrentBorealisPcbForMilling.FCStd]
2026-03-12 Milling success, saving changes
    [TrailCurrentBorealisPcbForMilling.FCStd]
2026-03-12 EDA in progrss for DIY board, single sided traces for early etching examples pior to ordering
2026-03-17 Switching to new temp and humdity sensor
    [TrailCurrentBorealis.kicad_pcb, TrailCurrentBorealis.kicad_sch]
2026-03-17 Updated PCB for DIY build
    [TrailCurrentBorealis.kicad_pcb, TrailCurrentBorealis.kicad_sch]
2026-03-17 One additional footprint change for DIY board
    [TrailCurrentBorealis.kicad_pcb]
2026-03-17 Ready for DIY manufacturing
    [TrailCurrentBorealis.kicad_pcb, TrailCurrentBorealisPcbForMilling.FCStd]
2026-03-17 Fixed pin assignments to align with EDA
2026-03-17 Working state with DIY board. Will revise with Mfg board soon.
    [TrailCurrentBorealis.kicad_pcb]
2026-03-18 Revised version of the case design. Grbls added for mfg
    [BodyBorealisCaseBottomV2.stl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]
2026-03-19 WIP EDA advancing the PCB further with better buck converter and reverse polarity protection
    [BodyBorealisCaseCoverV1.stl, BodyBorealisCaseCoverV2.stl, BodyBorealisCaseCoverV3.stl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]
2026-03-28 Aligned OTA and Discovery with Switchback
2026-03-28 Fixing issue with CAN Bus stops responding when discovery happens
    [main.c]
2026-03-28 Fixed bug with init that was causing TWAI not to send / receive
    [main.c, sensors.c]
2026-04-12 Adding discovery for this device
2026-05-04 Moving to new ESP32S3 and new sensors to provider broader range of coverage for air quality measurements.
    [partitions.csv]
2026-05-04 Adding todos for when the sensors arrive
2026-10-31 Fix SEN0466 CO decoding, make mDNS names unique, replace enclosure CAD
    Firmware:
    - SEN0466: read decimal places from response byte 5, not byte 4. Byte 4
    is the fixed gas-type ID (0x04 for CO), so the old code divided the
    raw reading by 10^4 and CO always came out near zero. Add logging of
    the raw response, plus cell voltage and board temperature every 5th
    read, for checking the sensor on the bench.
    - sensors_init_i2c() now returns ESP_ERR_NOT_FOUND when no I2C sensor
    answers, instead of always returning ESP_OK.
    - discovery: add the hostname to the mDNS instance and service names.
    Every module used to advertise the same name, so modules answering
    the same Scan collided and one c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
